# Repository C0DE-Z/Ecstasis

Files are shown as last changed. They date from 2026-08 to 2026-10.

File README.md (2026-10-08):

# Ecstasis Mk2
 *to stand outside oneself*

A Fuzz pedal based after the Electro-Harmonix Big Muff Pi V7 (Green Russian)

Powered by 9v battery or DC input 
using cheap and easy to source parts, trying to replacate the sound of the orginal somewhat closely. 

## Improvments from the Mk1
- Optmized track width for 9v powerline
- Fixxed Footprint for the 1/4 inch audio jacking being inverted
- Optimized Part location 
- Lowered VIA count
- Added silkscreen prints to show what each pot does, and for what is in and out.

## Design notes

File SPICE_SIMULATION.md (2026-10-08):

`BIG_MUFF_audio.cir` is an ngspice testbench transcribed from the audio
components and connections in `BIG_MUFF.kicad_sch`. It includes the four
BC547 gain stages, both antiparallel clipping pairs, the tone network, and
the sustain, tone, and volume controls.

## Run

Install ngspice, then run this from the project directory:

```text
ngspice -b BIG_MUFF_audio.cir
```

The deck writes `BIG_MUFF_ac.csv` (20 Hz–20 kHz response and gain),
`BIG_MUFF_stages.csv` (individual stage gains), and
`BIG_MUFF_nodes.csv` (AC node levels), and `BIG_MUFF_transient.csv` (50 ms at
1 kHz) to the current directory. To inspect the curves interactively, open the
deck in ngspice and use:

```text
source BIG_MUFF_audio.cir
```

The default transient input is a 25 mV peak, 1 kHz sine wave with 10 kOhm
source resistance; adjust `INPUT_PEAK` to test other pickup levels. The AC
analysis uses a 1 V small-signal source. Pot positions are parameters from 0
to 1 near the top of the deck: `SUSTAIN`, `TONE`, and `VOLUME`.

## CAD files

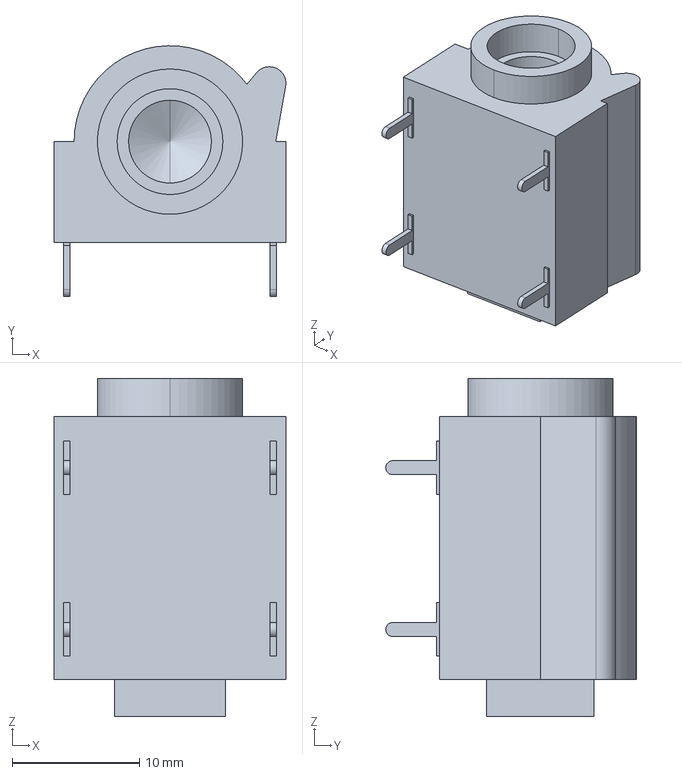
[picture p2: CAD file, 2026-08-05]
3d Models/d-nmj4hcd2.stp
18.2 x 19.7 x 26.5 mm

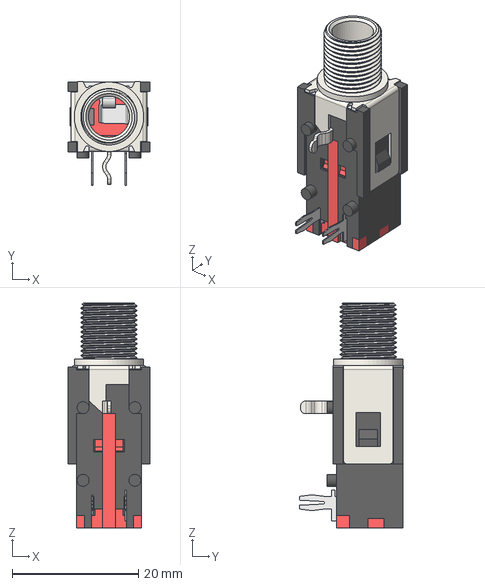
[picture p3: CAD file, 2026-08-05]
3d Models/Stereo jack 6.35.step
13.0 x 16.5 x 35.6 mm

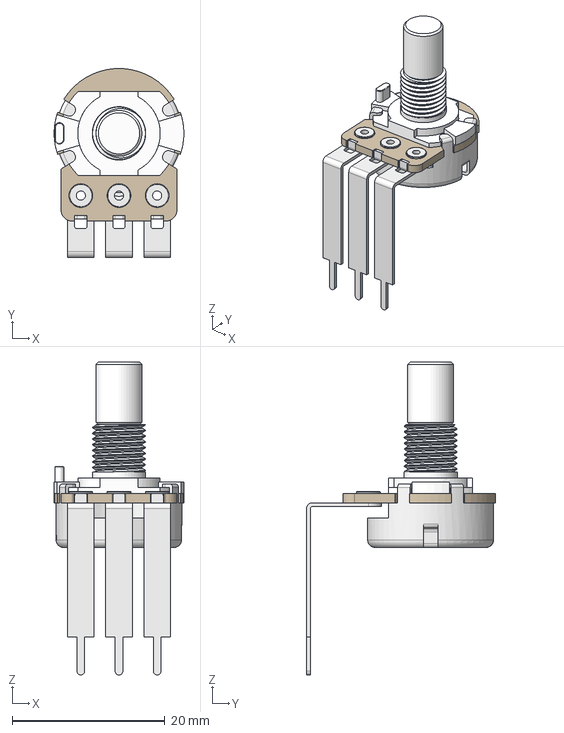
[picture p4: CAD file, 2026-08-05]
3d Models/RV16AF-41(LL).step
17.0 x 24.7 x 41.0 mm

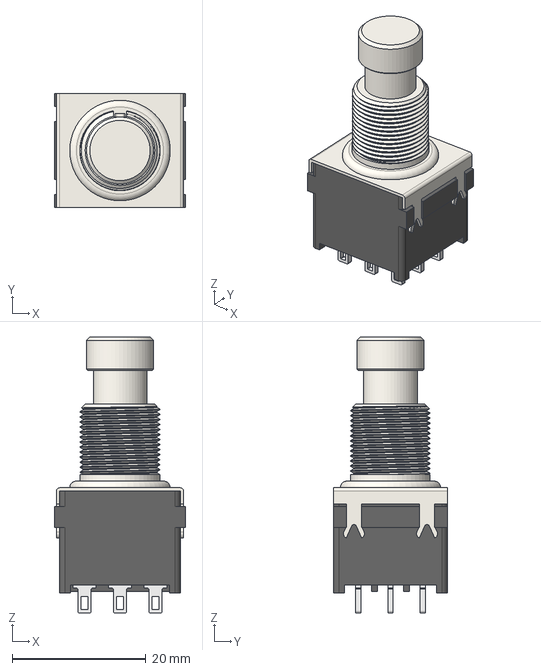
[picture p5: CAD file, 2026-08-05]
3d Models/SF17020F-0302-21R-L.step
19.6 x 17.0 x 41.2 mm

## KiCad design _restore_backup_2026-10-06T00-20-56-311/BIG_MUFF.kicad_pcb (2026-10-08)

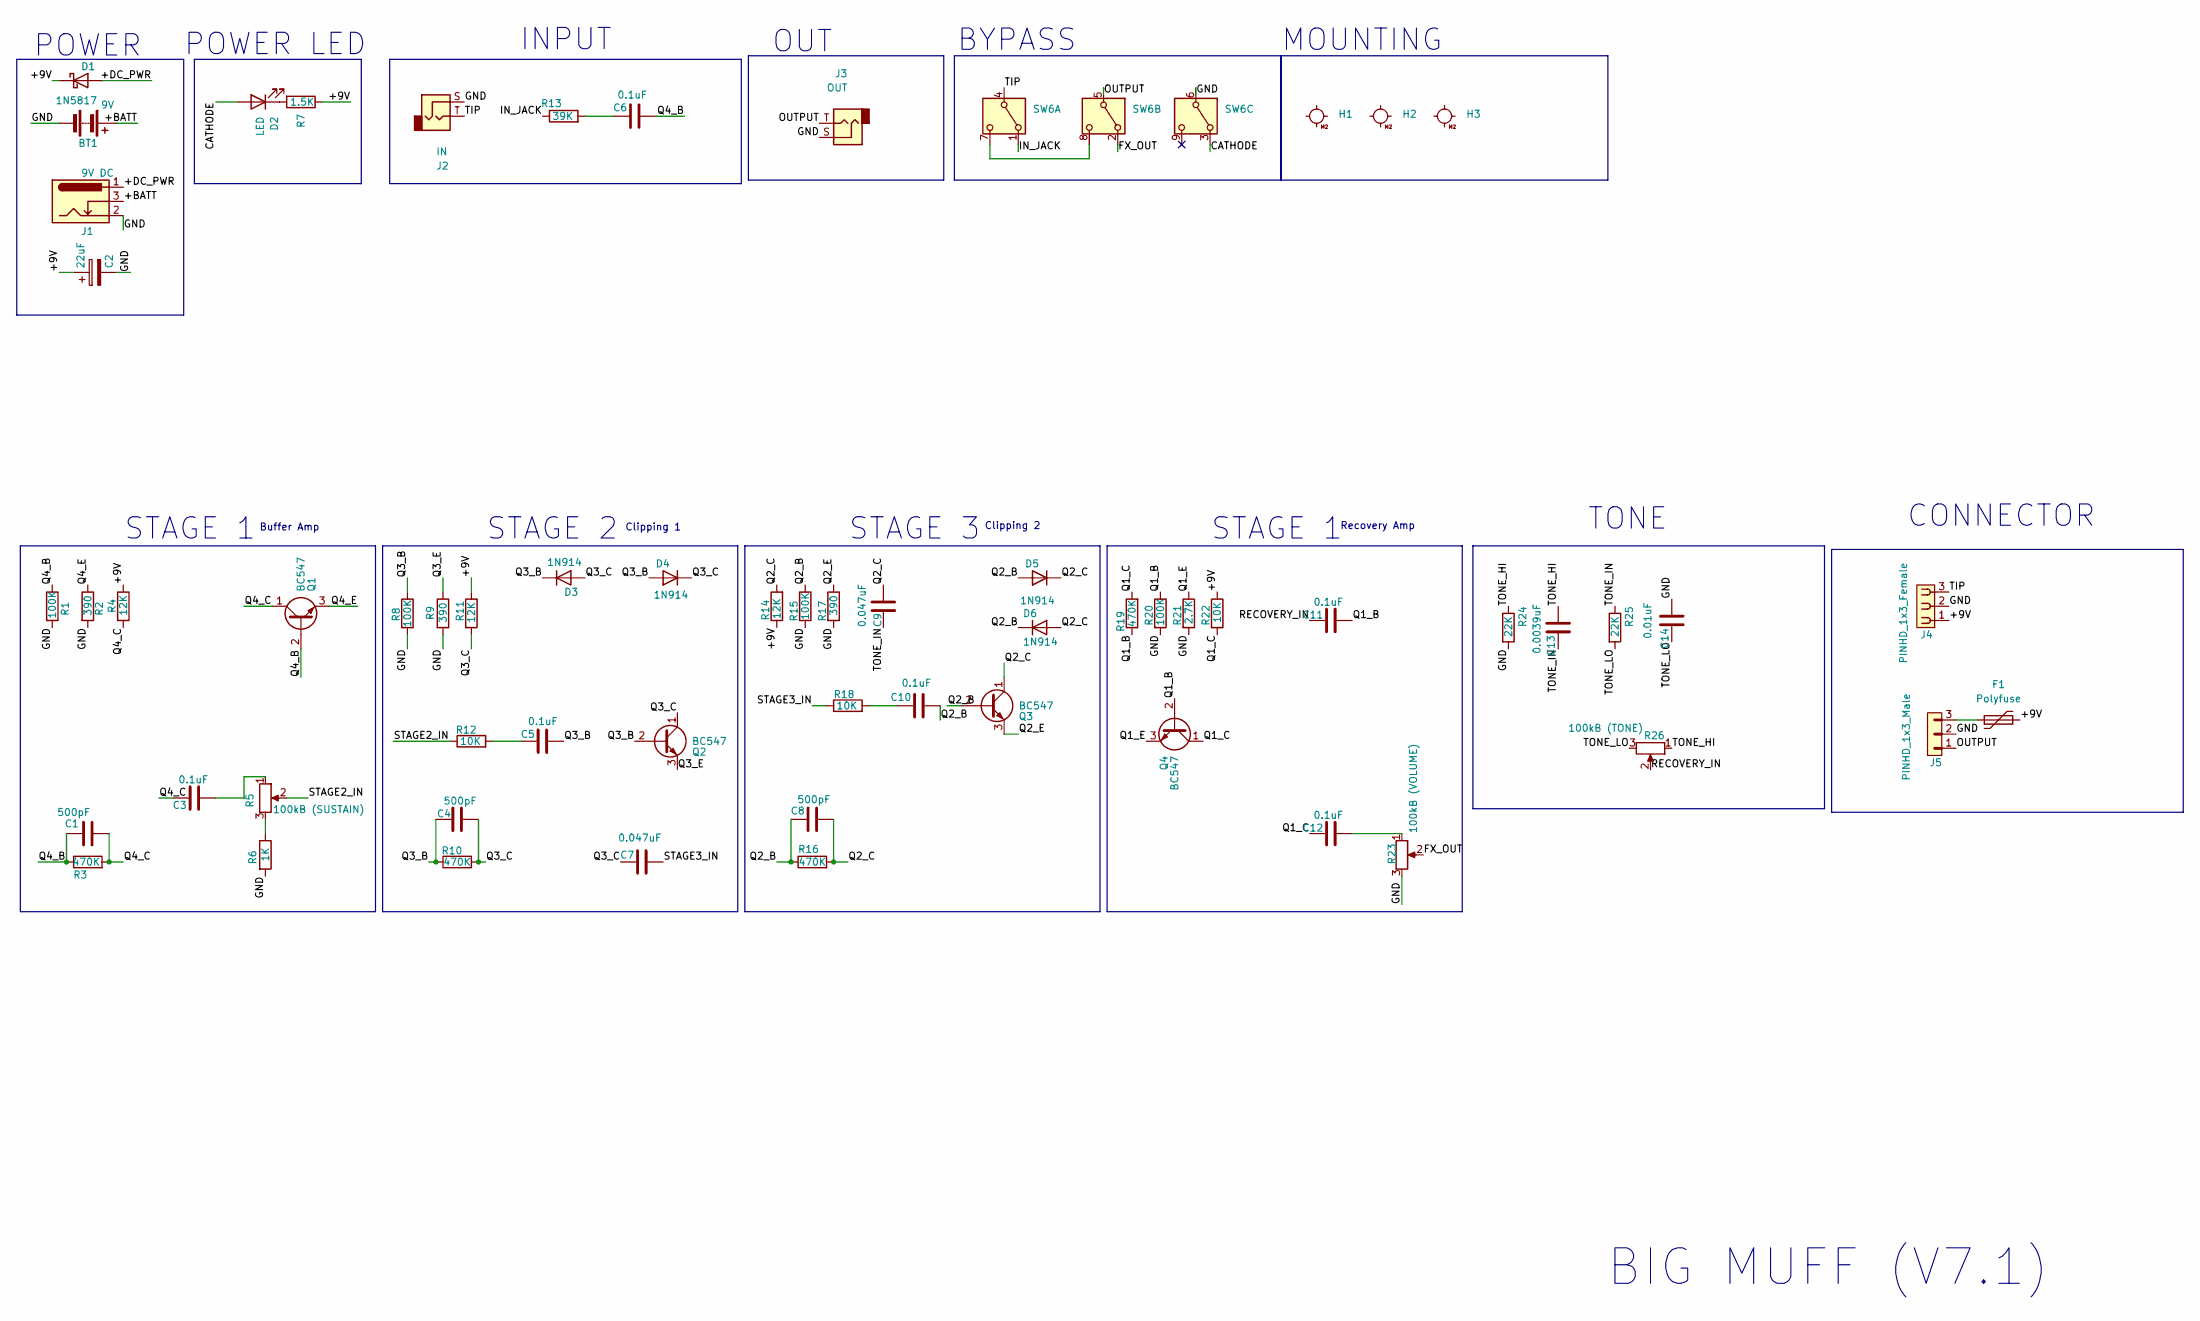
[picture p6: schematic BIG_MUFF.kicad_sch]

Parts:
BT1: 9V; SolderWire-0.75sqmm_1x02_P4.8mm_D1.25mm_OD2.3mm
C1, C4, C8: 500pF; C_Disc_D5.0mm_W2.5mm_P2.50mm
C2: 22uF; CP_Radial_D5.0mm_P2.00mm
C3, C5, C6, C10, C11, C12: 0.1uF; C_Rect_L7.0mm_W2.5mm_P5.00mm
C7, C9: 0.047uF; C_Rect_L7.0mm_W2.5mm_P5.00mm
C13: 0.0039uF; C_Rect_L7.0mm_W2.5mm_P5.00mm
C14: 0.01uF; C_Rect_L7.0mm_W2.5mm_P5.00mm
D1: 1N5817; D_DO-35_SOD27_P7.62mm_Horizontal
D2: LED; LED_D3.0mm
D3, D4, D6: 1N914; D_DO-35_SOD27_P7.62mm_Horizontal
D5: 1N914; D_DO-41_SOD81_P7.62mm_Horizontal
F1: Polyfuse; Fuse_Bourns_MF-RHT100
H1, H2, H3: MountingHole_M2
J1: 9V DC; BarrelJack_Horizontal
J2: IN; J_6.35mm_NMJ4HCD2_Custom
J3: OUT; J_6.35mm_NMJ4HCD2_Custom
J4: PINHD_1x3_Female; PinSocket_1x03_P2.54mm_Horizontal
J5: PINHD_1x3_Male; PinSocket_1x03_P2.54mm_Horizontal
Q1, Q2, Q3, Q4: BC547; TO-92_Inline
R1, R8, R15, R20: 100K; R_Axial_DIN0207_L6.3mm_D2.5mm_P7.62mm_Horizontal
R2, R9, R17: 390; R_Axial_DIN0207_L6.3mm_D2.5mm_P7.62mm_Horizontal
R3, R10, R16, R19: 470K; R_Axial_DIN0207_L6.3mm_D2.5mm_P7.62mm_Horizontal
R4, R11, R14: 12K; R_Axial_DIN0207_L6.3mm_D2.5mm_P7.62mm_Horizontal
R5: 100kB (SUSTAIN); Potentiometer_Alpha_RD901F-40-00D_Single_Vertical
R6: 1K; R_Axial_DIN0207_L6.3mm_D2.5mm_P7.62mm_Horizontal
R7: 1.5K; R_Axial_DIN0207_L6.3mm_D2.5mm_P7.62mm_Horizontal
R12, R18, R22: 10K; R_Axial_DIN0207_L6.3mm_D2.5mm_P7.62mm_Horizontal
R13: 39K; R_Axial_DIN0207_L6.3mm_D2.5mm_P7.62mm_Horizontal
R21: 2.7K; R_Axial_DIN0207_L6.3mm_D2.5mm_P7.62mm_Horizontal
R23: 100kB (VOLUME); Potentiometer_Alpha_RD901F-40-00D_Single_Vertical
R24, R25: 22K; R_Axial_DIN0207_L6.3mm_D2.5mm_P7.62mm_Horizontal
R26: 100kB (TONE); Potentiometer_Alpha_RD901F-40-00D_Single_Vertical
SW6: SW_3PDT_Footswitch; SW_3PDT_Footswitch_9Pin_Custom

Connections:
/+9V: C2.1, D1.1 (K), F1.2, J4.1, R4.1, R7.1, R11.1, R14.1, R22.1
/+BATT: BT1.1 (+), J1.3
/+DC_PWR: D1.2 (A), J1.1
/CATHODE: D2.2 (A), SW6.3 (A3)
/FX_OUT: R23.2, SW6.2 (A2)
/GND: BT1.2 (-), C2.2, C14.2, J1.2, J2.S, J3.S, J4.2, J5.2, R1.2, R2.2, R6.2, R8.2, R9.2, R15.2, R17.2, R20.2, R21.2, R23.3, R24.2, SW6.6 (COM3)
/IN_JACK: R13.1, SW6.1 (A1)
/OUTPUT: J3.T, J5.1, SW6.5 (COM2)
/Q1_B: C11.2, Q4.2 (B), R19.1, R20.1
/Q1_C: C12.1, Q4.1 (C), R19.2, R22.2
/Q1_E: Q4.3 (E), R21.1
/Q2_B: C8.1, C10.2, D5.2 (A), D6.1 (K), Q3.2 (B), R15.1, R16.1
/Q2_C: C8.2, C9.1, D5.1 (K), D6.2 (A), Q3.1 (C), R14.2, R16.2
/Q2_E: Q3.3 (E), R17.1
/Q3_B: C4.1, C5.2, D3.1 (K), D4.2 (A), Q2.2 (B), R8.1, R10.1
/Q3_C: C4.2, C7.1, D3.2 (A), D4.1 (K), Q2.1 (C), R10.2, R11.2
/Q3_E: Q2.3 (E), R9.1
/Q4_B: C1.1, C6.2, Q1.2 (B), R1.1, R3.1
/Q4_C: C1.2, C3.1, Q1.1 (C), R3.2, R4.2
/Q4_E: Q1.3 (E), R2.1
/RECOVERY_IN: C11.1, R26.2
/STAGE2_IN: R5.2, R12.1
/STAGE3_IN: C7.2, R18.1
/TIP: J2.T, J4.3, SW6.4 (COM1)
/TONE_HI: C13.2, R24.1, R26.1
/TONE_IN: C9.2, C13.1, R25.1
/TONE_LO: C14.1, R25.2, R26.3
unnamed: C3.2, R5.1
unnamed: C5.1, R12.2
unnamed: C6.1, R13.2
unnamed: C10.1, R18.2
unnamed: C12.2, R23.1
unnamed: D2.1 (K), R7.2
unnamed: F1.1, J5.3
unnamed: R5.3, R6.1
unnamed: SW6.7 (B1), SW6.8 (B2)

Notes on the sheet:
Recovery Amp
POWER
BIG MUFF (V7.1)
Buffer Amp
Clipping 2
CONNECTOR
INPUT
POWER LED
OUT
BYPASS
Clipping 1
STAGE 1
STAGE 3
MOUNTING
STAGE 2
TONE

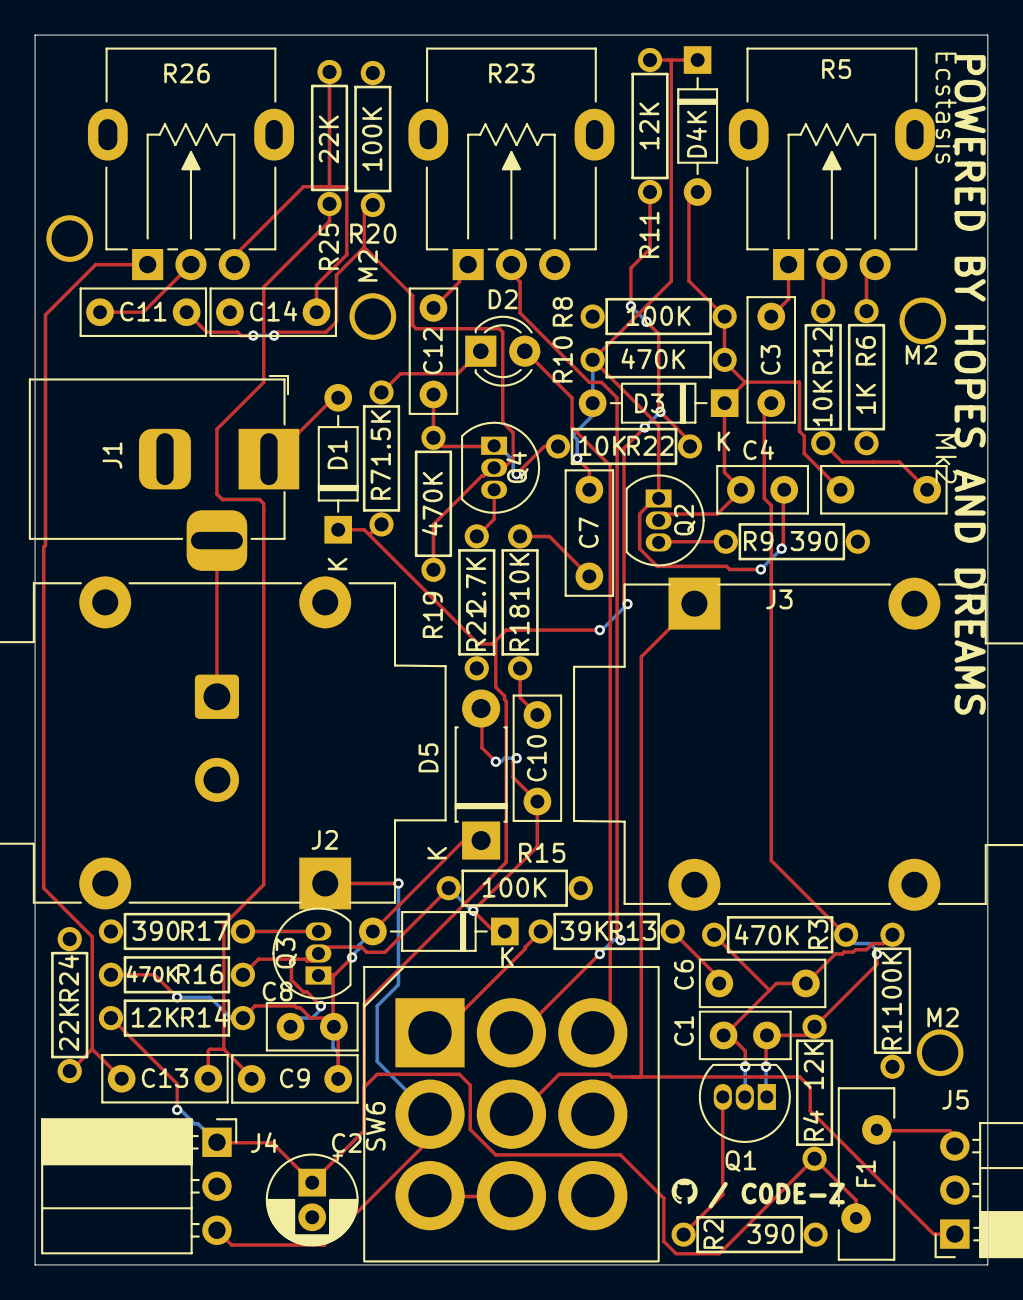
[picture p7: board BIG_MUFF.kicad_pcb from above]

Board: 2 copper layers, 55.0 x 71.0 mm, 61 parts (1 on the bottom side), 36 nets.

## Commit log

2026-08-06 DRM fix
    [BIG_MUFF-B_Cu.gbr, BIG_MUFF-B_Mask.gbr, BIG_MUFF-B_Paste.gbr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]
2026-08-13 prod ready for jcl
    [BIG_MUFF-B_Cu.gbr, BIG_MUFF-B_Mask.gbr, BIG_MUFF-B_Paste.gbr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]
2026-09-04 ready for jcl
    [BIG_MUFF.kicad_pcb, BIG_MUFF_GOOGLE_SHEETS_BOM.csv]
2026-09-24 fix routing
    [BIG_MUFF-B_Cu.gbr, BIG_MUFF-B_Mask.gbr, BIG_MUFF-B_Paste.gbr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]
2026-09-24 Fix Files
    [BIG_MUFF.dsn, RV16AF-41(LL).step, SF17020F-0302-21R-L.step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]
